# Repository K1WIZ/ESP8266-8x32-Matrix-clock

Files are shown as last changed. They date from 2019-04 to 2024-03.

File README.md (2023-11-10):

# ESP8266-8x32-Matrix-clock
ESP8266 Internet based clock using 8x32 MAX7219 FC16 Display

*** Improvements Welcome!  Just submit a pull request! ***

Improvements Desired:

1) ~~Use NTP to acquire time~~  DONE!
2) ~~Use WiFiManager to setup wifi and some user variables (ie. time offset float)~~  DONE!
3) ~~Add configurable option for 12hr time instead of 24hr - via wifimanager invokation~~  DONE!
4) ~~update code to work properly with ESP8266 Boards version 2.5.x and later~~

Video of clock in action: https://youtu.be/9C5dRMPiDTk

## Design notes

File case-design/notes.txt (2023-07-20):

DXF Files to make a case for the clock using 1/8" plexiglass.

Credit to Velin Dimitrov for the assistance generating these CAD drawings.  Without your help, this would have been much more difficult.

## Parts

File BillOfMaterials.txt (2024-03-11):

Parts List
To put this clock together, only a few parts are required. They are:

* Laser cut plexiglas case (drawing design files in the github repo)
* (4) M2x20mm hex spacers
* (4) M2x4mm hex spacers
* (8) M2x6mm hex cap screws
* (8) M2x4mm hex cap screws
* 8×32 LED FC16 Max7219 display
* Some hookup wire
* 2.1mm DC power jack
* Wemos D1 Mini ESP8266 WiFi microprocessor
* Wemos D1 Mini prototype sheild
* Super glue
* 6ft USB to 2.1mm barrel cable (for power)

Full kit ready to ship, if you don't want to source all these things yourself:
https://www.tindie.com/products/wizworks/wifi-time-machine-ntp-clock-kit

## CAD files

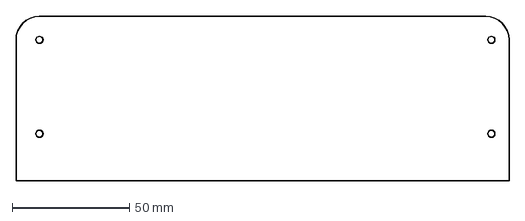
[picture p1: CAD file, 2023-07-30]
case-design/Front Plate.DXF
210.0 x 70.0 mm

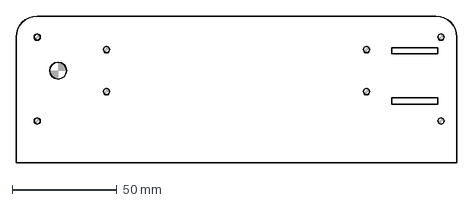
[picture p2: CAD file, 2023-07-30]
case-design/Rear Plate.DXF
210.0 x 70.0 mm

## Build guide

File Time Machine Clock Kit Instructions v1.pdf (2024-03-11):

# NTP Clock Kit Instructions

## First

Thank you for buying the kit! It is my hope that you get the satisfaction from enjoying putting this kit together. If you take your time, and avoid rushing, you will end up with a finished product that will bring you many years of enjoyment. This kit is designed for the intermediate skill level. Good soldering skill and technique will serve you well. I suggest the following tools to successfully put this kit together:
- Needle nose pliers
- Temperature controlled soldering station & solder
- Diagonal cutters
- Wire strippers
- A precision hex screwdriver set (metric)
- (optional) a lamp with magnifier (helpful when soldering)
Now, time to put on some background music, warm up the soldering iron (I suggest 500F), and let’s begin!

## Check All Parts

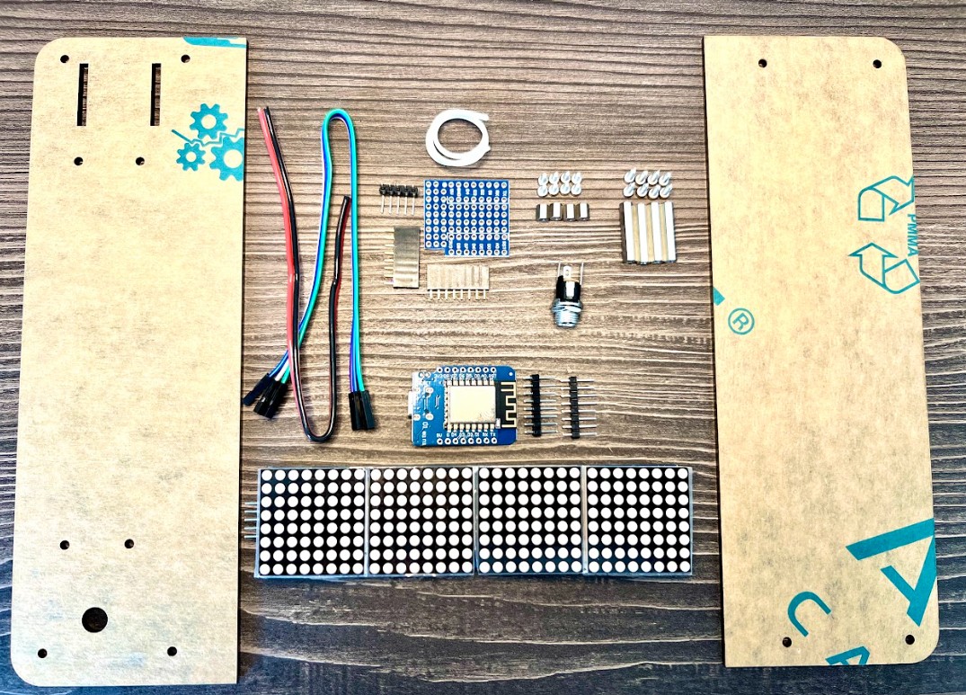
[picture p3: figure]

Before we begin, you’ll want to inventory the package of parts I sent you. Please refer to the picture above identifying all the components you’ll use to make your clock. You should have:
- front and back laser cut plexiglas plates
- 32x8 matrix display
- Wemos D1 Mini esp8266 MCU & two headers
- 2.1mm DC power socket
- length of power wire (red & black)
- length of data wire (5 conductor ribbon)
- length of hookup wire
- (4) M2 x 4mm hex spacers (for display mount) and (8) M2 4mm hex cap screws

- (4) M2 x 20mm hex spacers (front and back plate mounting) and (8) M2 6mm hex cap screws
- wemos prototype board shield with (2) female headers and (1) 5 pin 90-degree male header (This is used to build the wiring harness and MCU mount)

## The Wiring Harness/ESP8266 Socket

The first thing we’ll want to put together is the socket that the esp8266 (MCU) will sit in. This socket will also have the function of breaking out the connections so that power and data can flow between the MCU and the 32x8 matrix display. Here’s what the finished harness looks like: (please take care to build exactly as shown! This part will not work correctly if the board orientation is not exactly as shown!) First solder the 5 pin header aligned with the 5V labeled row as shown:

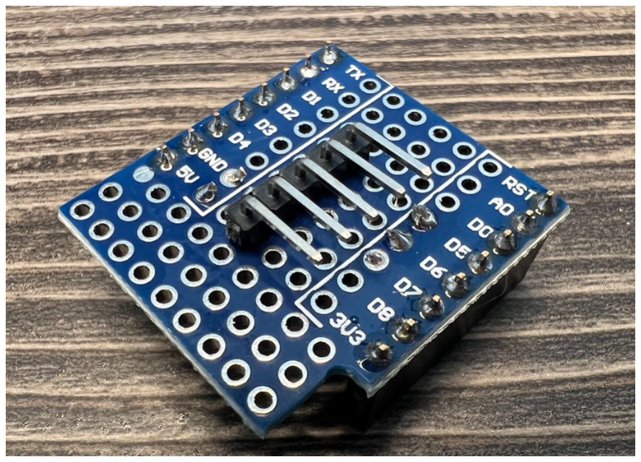
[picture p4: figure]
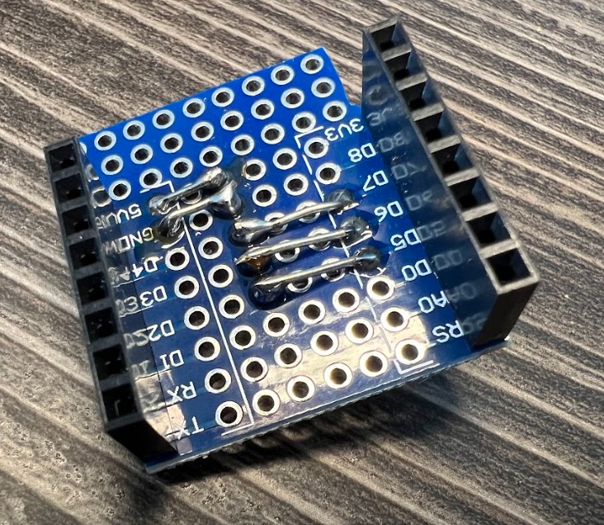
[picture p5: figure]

You can see that the bottom exposes the female headers and shows how I created “jumpers” by stripping the hookup wire (strip off a few inches and insert enough through the top as shown and bend it over to the correct pin from the 5 pin header. Do this AFTER you solder the 5 pin header on the top side ALIGNED starting with the “5V row.

## Install 4mm And 20mm Spacers As Shown

Before we can mount the wiring harness to the back plate (using super glue), we need to first install the spacers on the back plate. This helps create a nice gap between the plate and your working surface so air can flow and help cure the glue easier. Install spacers as shown below. Use the 4mm screws with the 4mm spacers and use the 6mm screws with the 20mm spacers. Use a needle nose pliers and hex precision screw driver to tighten the screws and spacers securely to the back plate. DO NOT OVER TIGHTEN!!!! take care NOT to scratch the plexiglas in this step.

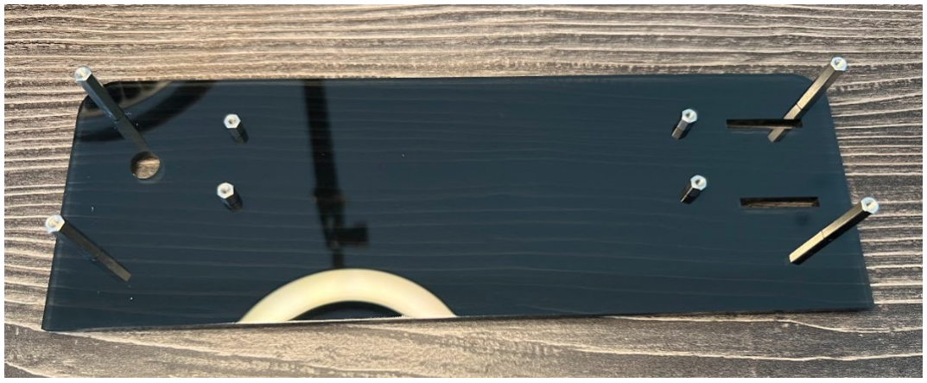
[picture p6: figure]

## It’s Time To Mount The Wiring Harness

Get your super glue and apply a conservative amount of glue along the inner sides of the female headers – the point that will contact the plexiglas. Take great care NOT to get the glue inside the pin holes! Once you apply the glue, you’ll need to use firm but careful pressure to insert the wiring harness headers into the slots (as shown) being careful not to get glue in the header pin holes. You want the insertion to go just deep enough that the harness header holes are FLUSH with the rear surface of the plate. BE VERY CAREFUL TO ENSURE THE ORIENTATION IS EXACTLY AS SHOWN!!

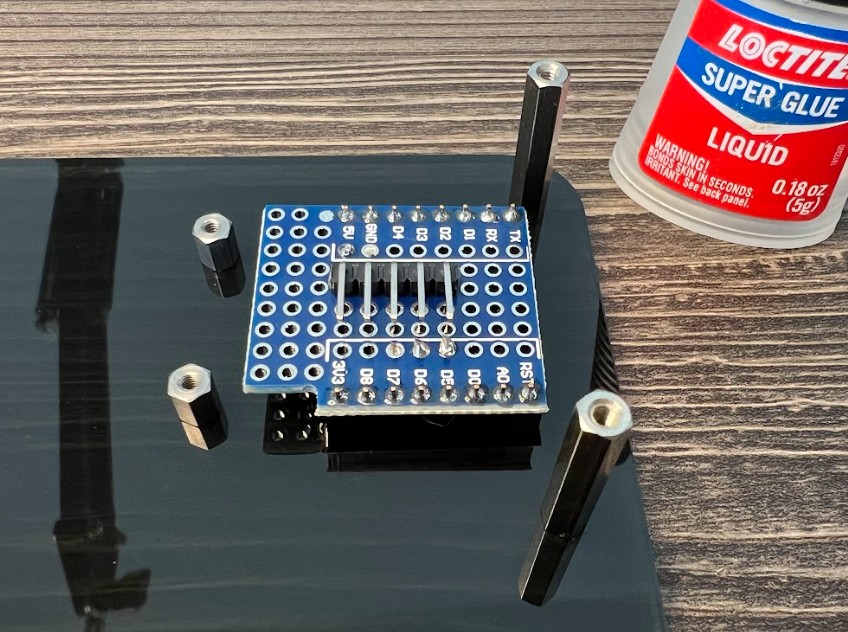
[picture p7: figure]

When you’re done mounting the harness, it should look like this on the other side:

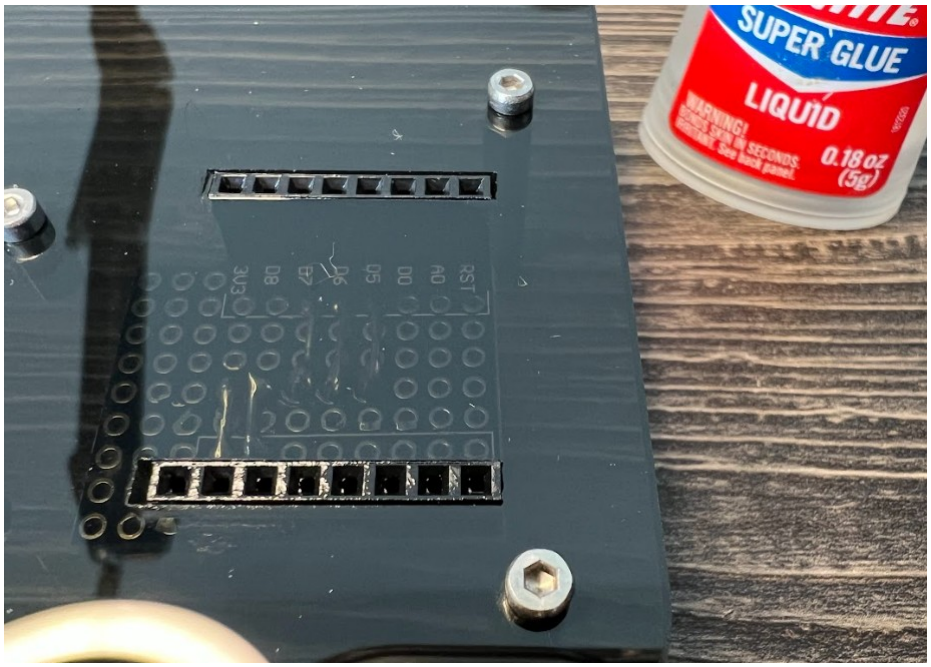
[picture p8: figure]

Once successfully mounting the harness, turn the plate over and rest it on your work area and leave for about an hour. After an hour, the glue should be well cured enough to continue building the kit. In the meantime, go enjoy a cup of coffee or whatever you fancy.

## Stripping/Preparing The Power Wire

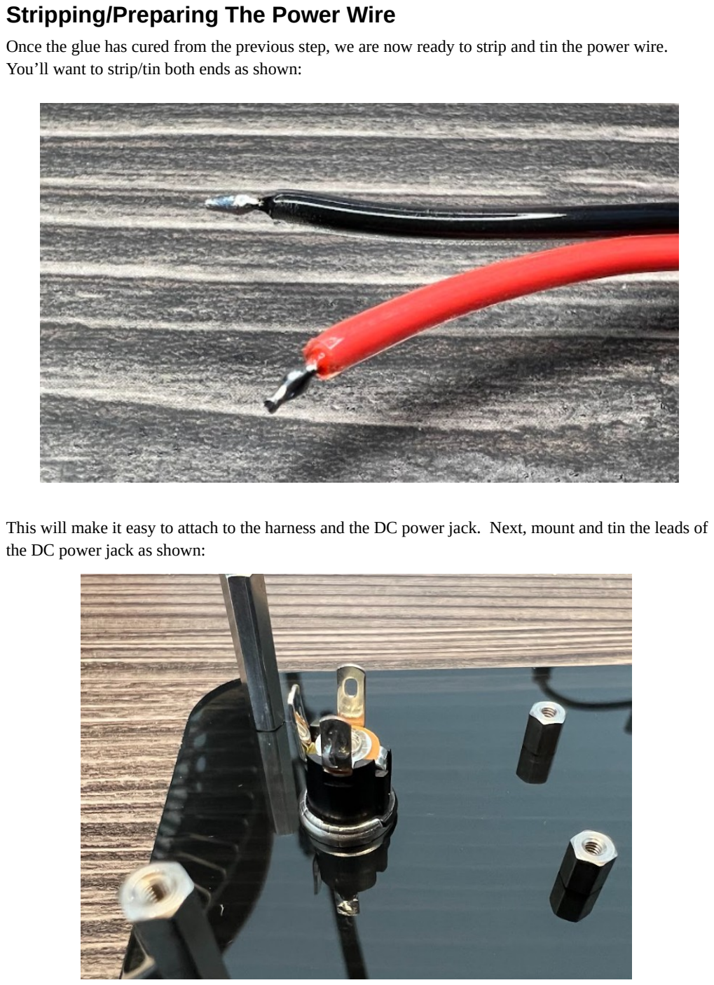
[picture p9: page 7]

Once the glue has cured from the previous step, we are now ready to strip and tin the power wire. You’ll want to strip/tin both ends as shown:

This will make it easy to attach to the harness and the DC power jack. Next, mount and tin the leads of the DC power jack as shown:

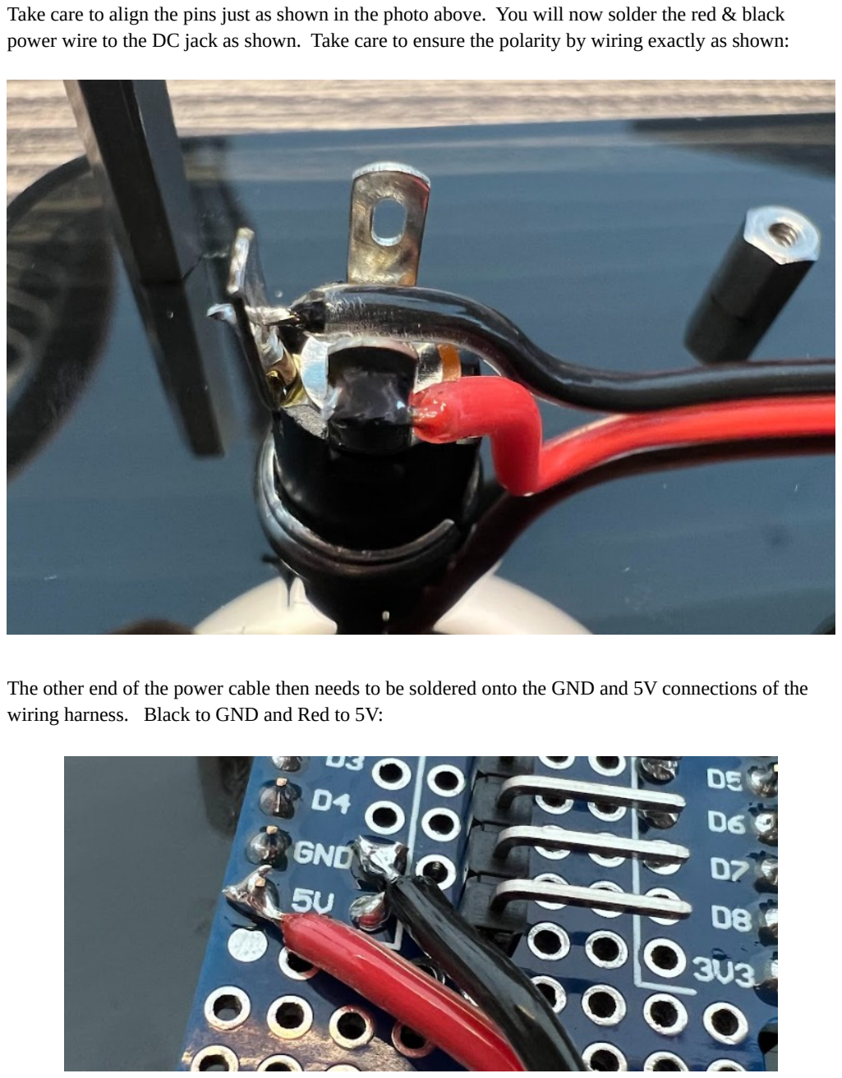
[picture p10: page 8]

Take care to align the pins just as shown in the photo above. You will now solder the red & black power wire to the DC jack as shown. Take care to ensure the polarity by wiring exactly as shown:

The other end of the power cable then needs to be soldered onto the GND and 5V connections of the wiring harness. Black to GND and Red to 5V:

## Mounting The Display

It’s time to mount the display! To do so, first remove the left and right 8x8 modules. This exposes the corner mounting holes. The 5 pins should be on the LEFT of the display near the DC jack.

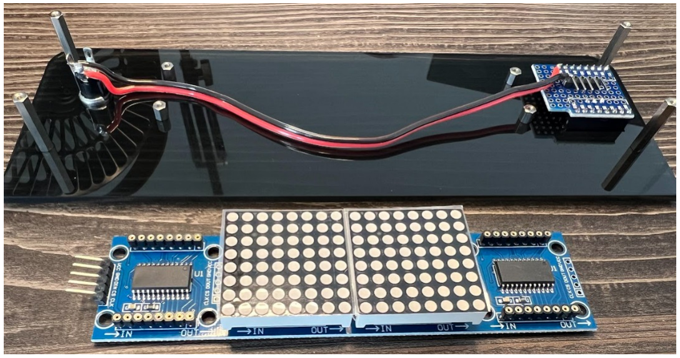
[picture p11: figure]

Don’t worry, they’ll be covered up when the data cable is connected. Position the display evenly as possible over the 4 4mm hex spacers. NOTE: you may wish to loosen the hex screws on these on the rear just a tad – as there is some wiggle room. Once you have the holes over the spacers as best as possible, it is time to put the data ribbon cable on the 5 pins on the left, and BEND IT HARD around the back of the display as shown: (take note what colors go to what pins!)

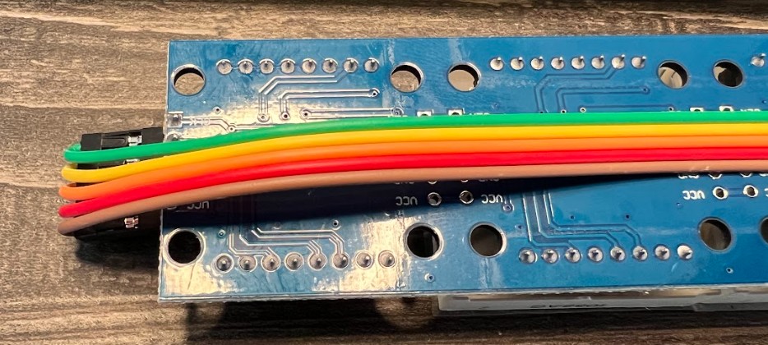
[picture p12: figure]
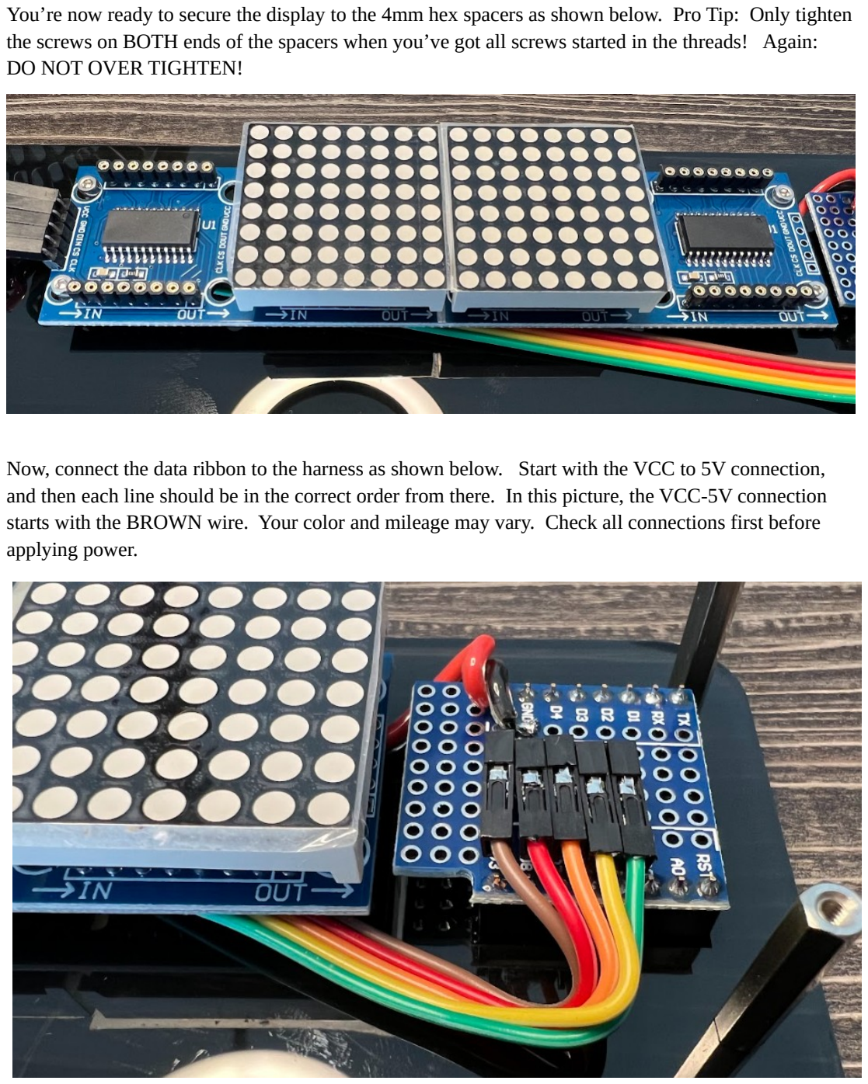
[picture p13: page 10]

You’re now ready to secure the display to the 4mm hex spacers as shown below. Pro Tip: Only tighten the screws on BOTH ends of the spacers when you’ve got all screws started in the threads! Again:
DO NOT OVER TIGHTEN!

Now, connect the data ribbon to the harness as shown below. Start with the VCC to 5V connection, and then each line should be in the correct order from there. In this picture, the VCC-5V connection starts with the BROWN wire. Your color and mileage may vary. Check all connections first before applying power.

Re-mount the two 8x8 display elements you removed from the previous steps. Note these are polarized. The elements have a little notch/tab in the top middle and they all need to appear as shown:

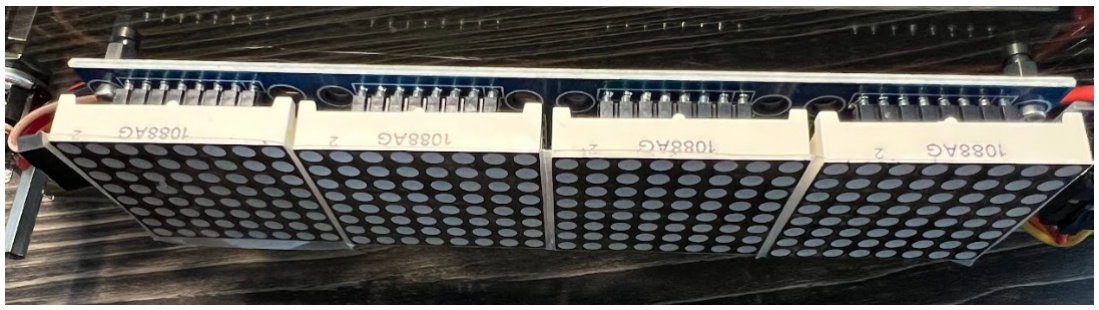
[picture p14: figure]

## The Home Stretch!

Breathe a sigh of relief! The worst is over! You are now ready to mount the front plexiglas plate. This step completes the build of this kit. Carefully remove the protective paper from both sides of the front plate. Take care to ensure you hold the plate by only the edges. This way you’ll avoid fingerprints and smudges on your new clock display. Use the remaining 6mm hex screws to secure the plate to the 20mm spacers. Only tighten after all screws have been threaded. Before final tightening, it is suggested to stand the clock upright on its bottom and hold it against the table while tightening these screws. This ensures that the plates secure evenly and that the clock will not wobble from uneven mounting.

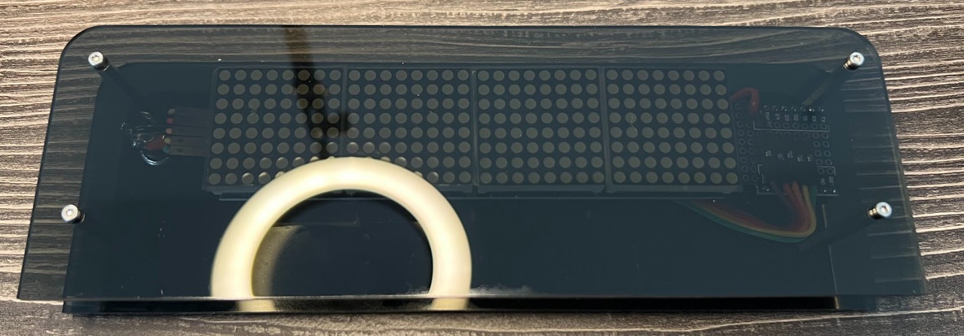
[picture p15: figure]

After the front plate is mounted, the last thing to do is to mount the esp8266 MCU. After soldering the header pins provided, onto the MCU, you then plug it in on the rear of the clock as shown on the next page.

NOTE: ONLY insert the MCU in the orientation shown!!!! Failure to do so WILL destroy the module! You’ve been warned!

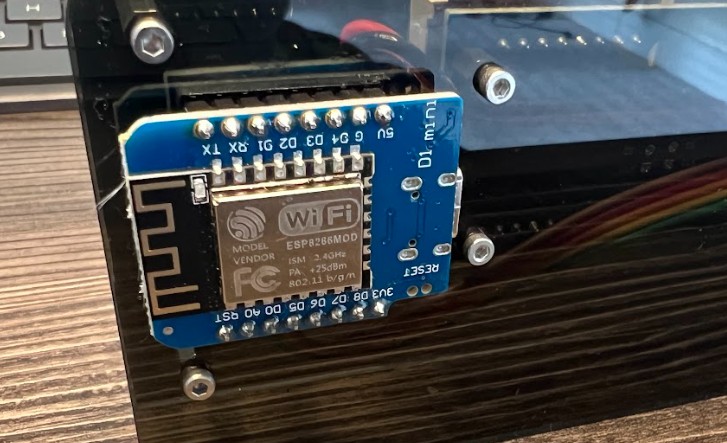
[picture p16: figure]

Note that the antenna end of the MCU is aligned with the edge of the clock.
Once installed, you can now apply power after checking all connections and begin the WiFi setup!

# Instructions on next page

# SETUP INSTRUCTIONS

## Step 1

Apply 5V DC power via the 2.1mm barrel jack on the rear side.

## Step 2

Using your phone or other mobile wifi device, search for the wifi network NTP Clock Setup. Once connected, you can scan for available networks (NOTE: only 2.4GHz is supported). Click on your network and enter the network password. Scroll to the bottom and enter your UTC offset for your region (half hour & 45 minute offsets are supported, so for example India, enter 5.5 in the offset. For New Zealand, enter 12.75). For Eastern Daylight: -4. Then click SAVE

## NOTE

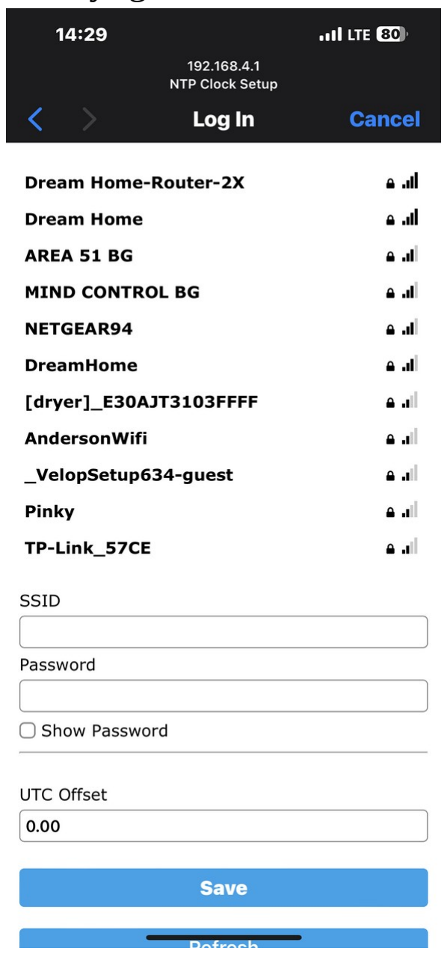
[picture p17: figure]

Moving the clock to another wireless network (where the previous network is no longer available) will make the clock begin the setup routine again. This allows the clock to be moved elsewhere and easily setup at a new location. If a move is not intended, but the clock is started in the absence of the original network, simply press the small reset button on the ESP8266 module when the original network is restored. Clock settings are stored in EEPROM. Note that sometimes, a bad NTP packet may be received. In such case, when this happens, you will see garbage on the display. Though this is rare, you can easily correct it by hitting the small reset button on the MCU and allow the clock to connect again. This can be caused by weak wifi signal, or poor internet connectivity.

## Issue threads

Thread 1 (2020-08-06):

Wrong timestamp if internet is not available.

Nono118, 2020-08-06:
I setup a wireless hotspot but turn OFF the internet access. Power up the clock, clock starts up, gets connected but starts time at 8:00. It should have shown a get time error coz e.g power trip will cause the time to be wrong.

K1WIZ, 2020-08-11:
Please feel free to submit a pull request and I will be happy to test it and merge it into the project.

K1WIZ, 2023-07-08:
Closing issue as this is not a typical use case.  Please feel free to submit a pull request against the latest master code.

Closed 2023-07-08.

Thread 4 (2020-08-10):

Date displayed sometimes is wrong.

Nono118, 2020-08-10:
`printStringWithShift(date.c_str(),40);  //Display date onto LED, shift delay 40`

This line which was originally //commented out// is meant to display the date every 30sec to the MAX7219.

There's a date bug in the way the code is written. The time & date are taken from a HTTP source which is at GMT=0. If you're outside of GMT=0, then your date will be wrong at certain times of the day, and gets corrected only when your timezone finally crosses GMT=0. This cannot be resolved, unless rewrite the code to use NTP style time fetching.

Someone must have knew it and //commented out// the date display function.

K1WIZ, 2020-08-11:
Please feel free to submit a pull request and I'll be happy to test it and merge it into the project  :)

K1WIZ, 2023-07-08:
this functionality has been removed from the project.  If you'd like to reintroduce it, please feel free to submit a pull request against the current master.

Closed 2023-07-08.

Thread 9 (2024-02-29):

Clock Display is Not Working

j-vaughn, 2024-02-29:
I just downloaded this project and wrote it to a Wemos D1 MIni with an MAX7219 attached.  The output to the screen with the function `printStringWithShift` works perfectly but when the clock comes up, it displays 00:00 for a split second (added a delay in `loop()` to see this) and then goes to gibberish.

Not sure if maybe there was a library update that broke something or if I'm just doing something wrong.

Thanks,
James

K1WIZ, 2024-03-10:
I'm unable to reproduce.   please ensure you are using the header max7219.h file packaged with this project.

Closed 2024-03-10.

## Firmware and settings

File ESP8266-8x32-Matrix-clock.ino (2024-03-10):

/*
 * ESP8266 NTP Clock is written by John Rogers.
 * john@wizworks.net
 * 
 * Permission for use is free to all, with the only condition that this notice is intact within
 * all copies or derivatives of this code.  Improvements are welcome by pull request on the github
 * master repo.  
 * 
 * ESP8266 NTP Clock:  https://github.com/K1WIZ/ESP8266-8x32-Matrix-clock
 * 
 */
#include "Arduino.h"
#include <ESP8266WiFi.h>
#include <DNSServer.h>
#include <ESP8266WebServer.h>
#include <WiFiManager.h>
#include <ArduinoJson.h>
#include <EEPROM.h>
#include <NTPClient.h>
#include <WiFiUdp.h>
#include <time.h> 

#define MAX_DIGITS 16
byte dig[MAX_DIGITS] = { 0 };
byte digold[MAX_DIGITS] = { 0 };
byte digtrans[MAX_DIGITS] = { 0 };
bool is12HFormat = true;
bool isPM = false;
int updCnt = 0;
int dots = 0;
long dotTime = 0;
long clkTime = 0;
int dx = 0;
int dy = 0;
byte del = 0;
int h, m, s;
float utcOffset; // UTC - Now set via WiFi Manager!
long epoch;
long localMillisAtUpdate;
int day, month, year, dayOfWeek;
int adjustedHour;
String clockHostname = "NTP-Clock";
WiFiManagerParameter custom_utc_offset("utcoffset", "UTC Offset", String(utcOffset).c_str(), 10);
WiFiManagerParameter custom_is_12h("is12h", "12 Hour Format", "true", 6);
WiFiManager wifiManager;

WiFiUDP ntpUDP;
NTPClient timeClient(ntpUDP, "pool.ntp.org", 0); // utcOffsetInSeconds will be dynamically adjusted

#define NUM_MAX 4
#define DIN_PIN 13
#define CS_PIN 12
#define CLK_PIN 14
#include "max7219.h"
#include "fonts.h"
#define UTC_OFFSET_ADDRESS 0

void setup() {
  Serial.begin(115200);
  // Initialize EEPROM
  EEPROM.begin(sizeof(float));
  wifiManager.setSaveParamsCallback(saveConfigCallback);
  wifiManager.addParameter(&custom_utc_offset);
  wifiManager.addParameter(&custom_is_12h);
  WiFi.mode(WIFI_STA);
  initMAX7219();
  sendCmdAll(CMD_SHUTDOWN, 1);
  sendCmdAll(CMD_INTENSITY, 0);
  Serial.print("Connecting WiFi ");
  WiFi.hostname(clockHostname.c_str());

  if (!wifiManager.autoConnect("NTP Clock Setup")) {
    Serial.println("Failed to connect and hit timeout");
    delay(3000);
    ESP.restart();
    delay(5000);
  }

  utcOffset = atof(custom_utc_offset.getValue());

  printStringWithShift("Connecting", 15);
  while (WiFi.status() != WL_CONNECTED) {
    delay(500);
    Serial.print(".");
  }

  // Read the utcOffset value from EEPROM
  EEPROM.get(UTC_OFFSET_ADDRESS, utcOffset);

  Serial.println("");
  Serial.print("MyIP: ");
  Serial.println(WiFi.localIP());
  Serial.print("UTC Offset: ");
  Serial.println(utcOffset);
  printStringWithShift((String("  MyIP: ") + WiFi.localIP().toString()).c_str(), 15);
  delay(1500);
  // Start NTP Client
  timeClient.begin();
}

// =======================================================================

void saveConfigCallback() {
  utcOffset = atof(custom_utc_offset.getValue());
  is12HFormat = String(custom_is_12h.getValue()) != "false";

  // Store the utcOffset value in EEPROM
  EEPROM.put(UTC_OFFSET_ADDRESS, utcOffset);
  EEPROM.commit();
}

// =======================================================================
void loop() {
  if (updCnt <= 0) {  // every 10 scrolls, ~450s=7.5m
    updCnt = 60;
    Serial.println("Getting data ...");
    printStringWithShift("   Setting Time...", 15);
    getTime();
    Serial.println("Data loaded");
    clkTime = millis();
  }

  if (millis() - clkTime > 20000 && !del && dots) {  // clock for 15s, then scrolls for about 30s
    updCnt--;
    clkTime = millis();
  }
  if (millis() - dotTime > 500) {
    dotTime = millis();
    dots = !dots;
  }
  updateTime(epoch, localMillisAtUpdate);
  setIntensity();
  showAnimClock();
}

// =======================================================================
void setIntensity() {
  int intensityHour = h; // Always use the hour in 24-hour format for intensity decisions

  // No need to adjust intensityHour based on is12HFormat

  // Set intensity based on the 24-hour format hour
  if (intensityHour >= 22 || intensityHour < 6) {
    sendCmdAll(CMD_INTENSITY, 0);  // Low intensity for night time
  } else if ((intensityHour >= 7 && intensityHour <= 10) || (intensityHour >= 16 && intensityHour < 18)) {
    sendCmdAll(CMD_INTENSITY, 3);  // Medium intensity for morning and late afternoon
  } else if (intensityHour >= 11 && intensityHour <= 15) {
    sendCmdAll(CMD_INTENSITY, 5);  // High intensity for midday
  } else if (intensityHour >= 19 && intensityHour <= 22) {
    sendCmdAll(CMD_INTENSITY, 2);  // Lower intensity for evening
  }
}

// =======================================================================

void showAnimClock() {
  byte digPos[6] = { 0, 8, 17, 25, 34, 42 };
  int digHt = 12;
  int num = 6;
  int i;
  if (del == 0) {
    del = digHt;
    for (i = 0; i < num; i++) digold[i] = dig[i];

    int displayHour = h; // Use a temporary variable for the hour to be displayed
    
    // Adjust for 12H format if needed
    if (is12HFormat) {
      isPM = displayHour >= 12; // Determine if it's PM for potential AM/PM display
      displayHour %= 12;
      displayHour = displayHour ? displayHour : 12; // Converts 0 to 12 for 12-hour format display
    }

    // Prepare the digits based on the displayHour
    dig[0] = displayHour / 10 ? displayHour / 10 : (is12HFormat ? 10 : 0); // Leading 0 for 24H format, blank for 12H
    dig[1] = displayHour % 10;
    dig[2] = m / 10;
    dig[3] = m % 10;
    dig[4] = s / 10;
    dig[5] = s % 10;
    
    for (i = 0; i < num; i++) digtrans[i] = (dig[i] == digold[i]) ? 0 : digHt;
  } else {
    del--;
  }

  clr();
  for (i = 0; i < num; i++) {
    if (digtrans[i] == 0) {
      dy = 0;
      showDigit(dig[i], digPos[i], dig6x8);
    } else {
      dy = digHt - digtrans[i];
      showDigit(digold[i], digPos[i], dig6x8);
      dy = -digtrans[i];
      showDigit(dig[i], digPos[i], dig6x8);
      digtrans[i]--;
    }
  }
  dy = 0;
  // Handle the display of dots for seconds or AM/PM indicator
  setCol(15, dots ? B00100100 : 0);
  setCol(32, dots ? B00100100 : 0);
  refreshAll();
  delay(30);
}


// =======================================================================

void showDigit(char ch, int col, const uint8_t* data) {
  if (dy<-8 | dy> 8) return;
  int len = pgm_read_byte(data);
  int w = pgm_read_byte(data + 1 + ch * len);
  col += dx;
  for (int i = 0; i < w; i++)
    if (col + i >= 0 && col + i < 8 * NUM_MAX) {
      byte v = pgm_read_byte(data + 1 + ch * len + 1 + i);
      if (!dy) scr[col + i] = v;
      else scr[col + i] |= dy > 0 ? v >> dy : v << -dy;
    }
}

// =======================================================================

void setCol(int col, byte v) {
  if (dy<-8 | dy> 8) return;
  col += dx;
  if (col >= 0 && col < 8 * NUM_MAX)
    if (!dy) scr[col] = v;
    else scr[col] |= dy > 0 ? v >> dy : v << -dy;
}

// =======================================================================

int showChar(char ch, const uint8_t* data) {
  int len = pgm_read_byte(data);
  int i, w = pgm_read_byte(data + 1 + ch * len);
  for (i = 0; i < w; i++)
    scr[NUM_MAX * 8 + i] = pgm_read_byte(data + 1 + ch * len + 1 + i);
  scr[NUM_MAX * 8 + i] = 0;
  return w;
}


// =======================================================================

void printCharWithShift(unsigned char c, int shiftDelay) {
  if (c < ' ' || c > '~' + 25) return;
  c -= 32;
  int w = showChar(c, font);
  for (int i = 0; i < w + 1; i++) {
    delay(shiftDelay);
    scrollLeft();
    refreshAll();
  }
}

// =======================================================================

void printStringWithShift(const char* s, int shiftDelay) {
  while (*s) {
    printCharWithShift(*s, shiftDelay);
    s++;
  }
}
// =======================================================================

long getTime() {
  timeClient.update(); // Update time with NTP server

  // Apply the utcOffset to adjust for the local timezone
  epoch = timeClient.getEpochTime() + (long)(utcOffset * 3600);
  localMillisAtUpdate = millis(); // Store the current millis() to calculate the drift

  // Convert the adjusted epoch time to tm struct for local time
  time_t rawTime = epoch;
  struct tm *ptm = gmtime(&rawTime); // Convert epoch to struct tm as UTC time

  // Update global time variables
  h = ptm->tm_hour; // 24-hour format
  m = ptm->tm_min;
  s = ptm->tm_sec;

  // Update global date variables
  year = ptm->tm_year + 1900; // Year since 1900
  month = ptm->tm_mon + 1;    // tm_mon is months since January (0-11)
  day = ptm->tm_mday;         // Day of the month

  // Log the epoch time for debugging
  Serial.println(epoch);

  return epoch;
}



// =======================================================================

// Function to check if the current time is within daylight saving time
bool isDST(int day, int month, int year) {
  if (month > 3 && month < 10) {
    // DST is in effect between the second Sunday in March and the first Sunday in November
    if (month == 3 && day >= 8 - ((5 * year / 4 + 1) % 7)) return true;
    if (month == 11 && day <= 1 - ((5 * year / 4 + 1) % 7)) return true;
    if (month > 3 && month < 11) return true;
  }
  return false;
}

void updateTime(long epoch, long localMillisAtUpdate) {
  // Assuming utcOffset is correctly set from the WiFi Manager as -4
  // and considering the need to correctly apply this offset

  // Adjust epoch for the UTC offset
  //epoch += utcOffset * 3600; // This should subtract 4 hours worth of seconds from the epoch

  // Adjust for any time passed since the last NTP update to maintain accuracy
  epoch += (millis() - localMillisAtUpdate) / 1000;

  // Convert the adjusted epoch time to a tm structure for easier manipulation
  time_t adjustedEpoch = static_cast<time_t>(epoch);
  struct tm *timeinfo = gmtime(&adjustedEpoch); // Use gmtime here to work with the adjusted epoch directly

  // Update the global time variables based on the adjusted time
  h = timeinfo->tm_hour; // Should reflect the correct local time considering the utcOffset
  m = timeinfo->tm_min;
  s = timeinfo->tm_sec;

  // With is12HFormat = false, no need to convert h to 12-hour format, it should display directly as 24-hour format
  // Ensure that wherever the time is displayed, it uses h, m, s directly without further conversion

  // Debug print to verify the time after adjustment
  Serial.print("Adjusted Time: ");
  Serial.print(h);
  Serial.print(":");
  Serial.print(m);
  Serial.println(" (24-hour format)");
}

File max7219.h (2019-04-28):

// MAX7219 functions by Pawel A. Hernik
// 2016.12.10 updated for rotated LED Martices, define ROTATE below (0,90 or 270)

// MAX7219 commands:
#define CMD_NOOP   0
#define CMD_DIGIT0 1
#define CMD_DIGIT1 2
#define CMD_DIGIT2 3
#define CMD_DIGIT3 4
#define CMD_DIGIT4 5
#define CMD_DIGIT5 6
#define CMD_DIGIT6 7
#define CMD_DIGIT7 8
#define CMD_DECODEMODE  9
#define CMD_INTENSITY   10
#define CMD_SCANLIMIT   11
#define CMD_SHUTDOWN    12
#define CMD_DISPLAYTEST 15

byte scr[NUM_MAX*8 + 8]; // +8 for scrolled char

void sendCmd(int addr, byte cmd, byte data)
{
  digitalWrite(CS_PIN, LOW);
  for (int i = NUM_MAX-1; i>=0; i--) {
    shiftOut(DIN_PIN, CLK_PIN, MSBFIRST, i==addr ? cmd : 0);
    shiftOut(DIN_PIN, CLK_PIN, MSBFIRST, i==addr ? data : 0);
  }
  digitalWrite(CS_PIN, HIGH);
}

void sendCmdAll(byte cmd, byte data)
{
  digitalWrite(CS_PIN, LOW);
  for (int i = NUM_MAX-1; i>=0; i--) {
    shiftOut(DIN_PIN, CLK_PIN, MSBFIRST, cmd);
    shiftOut(DIN_PIN, CLK_PIN, MSBFIRST, data);
  }
  digitalWrite(CS_PIN, HIGH);
}

void refresh(int addr) {
  for (int i = 0; i < 8; i++)
    sendCmd(addr, i + CMD_DIGIT0, scr[addr * 8 + i]);
}

void refreshAllRot270() {
  byte mask = 0x01;
  for (int c = 0; c < 8; c++) {
    digitalWrite(CS_PIN, LOW);
    for(int i=NUM_MAX-1; i>=0; i--) {
      byte bt = 0;
      for(int b=0; b<8; b++) {
        bt<<=1;
        if(scr[i * 8 + b] & mask) bt|=0x01;
      }
      shiftOut(DIN_PIN, CLK_PIN, MSBFIRST, CMD_DIGIT0 + c);
      shiftOut(DIN_PIN, CLK_PIN, MSBFIRST, bt);
    }
    digitalWrite(CS_PIN, HIGH);
    mask<<=1;
  }
}

void refreshAllRot90() {
  byte mask = 0x80;
  for (int c = 0; c < 8; c++) {
    digitalWrite(CS_PIN, LOW);
    for(int i=NUM_MAX-1; i>=0; i--) {
      byte bt = 0;
      for(int b=0; b<8; b++) {
        bt>>=1;
        if(scr[i * 8 + b] & mask) bt|=0x80;
      }
      shiftOut(DIN_PIN, CLK_PIN, MSBFIRST, CMD_DIGIT0 + c);
      shiftOut(DIN_PIN, CLK_PIN, MSBFIRST, bt);
    }
    digitalWrite(CS_PIN, HIGH);
    mask>>=1;
  }
}

#define ROTATE 90

void refreshAll() {
#if ROTATE==270
  refreshAllRot270();
#elif ROTATE==90
  refreshAllRot90();
#else
  for (int c = 0; c < 8; c++) {
    digitalWrite(CS_PIN, LOW);
    for(int i=NUM_MAX-1; i>=0; i--) {
      shiftOut(DIN_PIN, CLK_PIN, MSBFIRST, CMD_DIGIT0 + c);
      shiftOut(DIN_PIN, CLK_PIN, MSBFIRST, scr[i * 8 + c]);
    }
    digitalWrite(CS_PIN, HIGH);
  }
#endif
}


void clr()
{
  for (int i = 0; i < NUM_MAX*8; i++) scr[i] = 0;
}

void scrollLeft()
{
  for(int i=0; i < NUM_MAX*8+7; i++) scr[i] = scr[i+1];
}

void invert()
{
  for (int i = 0; i < NUM_MAX*8; i++) scr[i] = ~scr[i];
}

void initMAX7219()
{
  pinMode(DIN_PIN, OUTPUT);
  pinMode(CLK_PIN, OUTPUT);
  pinMode(CS_PIN, OUTPUT);
  digitalWrite(CS_PIN, HIGH);
  sendCmdAll(CMD_DISPLAYTEST, 0);
  sendCmdAll(CMD_SCANLIMIT, 7);
  sendCmdAll(CMD_DECODEMODE, 0);
  sendCmdAll(CMD_INTENSITY, 0); // minimum brightness
  sendCmdAll(CMD_SHUTDOWN, 0);
  clr();
  refreshAll();
}

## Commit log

2019-04-28 corrected file name issue
    [ESP8266-8x32-Matrix-clock.ino]
2023-07-09 Update ESP8266-8x32-Matrix-clock.ino
    made corrections on updateTime & setIntensity
    [ESP8266-8x32-Matrix-clock.ino]
2023-07-09 Update ESP8266-8x32-Matrix-clock.ino
    fixed setIntensity and set dimming to adjustedHour
    [ESP8266-8x32-Matrix-clock.ino]
2023-07-30 Add files via upload
    changed 2mm holes to 3mm
    [Front Plate.DXF, Rear Plate.DXF]
2023-08-18 Update ESP8266-8x32-Matrix-clock.ino
    changed display data pin assignment.
2023-11-06 Update ESP8266-8x32-Matrix-clock.ino
    code correction to fix DST.
    [ESP8266-8x32-Matrix-clock.ino]
2023-11-06 Update ESP8266-8x32-Matrix-clock.ino
    Removed unecessary code that wasn't used for the DST calculation, since it was corrected with an earlier update.
    [ESP8266-8x32-Matrix-clock.ino]
2023-11-27 Update ESP8266-8x32-Matrix-clock.ino
    Fixed display intensity code
    [ESP8266-8x32-Matrix-clock.ino]
2024-03-10 DST correction
    updated DST logic as previous logic did not work to adjust the clock to DST changes. There will be a future update to toggle whether to honor DST or not.
    [ESP8266-8x32-Matrix-clock.ino]
